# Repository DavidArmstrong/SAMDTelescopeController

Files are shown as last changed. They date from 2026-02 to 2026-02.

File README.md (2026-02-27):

# SAMDTelescopeController

## Arduino SAMD51-based Telescope Controller 4.00.00

### Main Repository Readme File

#### By David Armstrong, December 2025
 - See MIT LICENSE file

========================================================================

Note: This project is unfinished, although most of the work has been done.  I'm making it public 
so others can build on this framework. I'll continue to improve it, as I'm able to squeeze out
a few precious milliseconds over the coming months and years.

This repository implements one of many possible design scenarios for a Telescope Controller, 
using the Arduino IDE as a development environment.  It's purpose is to allow me, personally,
to use my telescope to look at stuff, instead of spending a lot of time setting it up.

I'm making this available for others to use as a reference in designing their own systems.  As
such, feel free to clone it and change as your needs dictate.

## Organization of the Repository

There are several directories in this project, each containing relevant information and code:

 - docs : Contains nearly all related documentation files for the system. (The Arduino sketches have their own Readme files.) There is a Draw.io based PNG image file showing the basic buiding blocks that make up the system, and how all the parts communicate with each other.
 - Arduino_Telescope_Interface : Eagle schematic of how to connect various interfaces.  If you have the Eagle PCB software installed, this directory should be copied to be a subdirectory under the EAGLE/projects/ directory.
 - TC4_0diagnostics : Arduino sketch designed to be used as a precursor sketch to TC4_0.  It's purpose is to help make sure all the needed software libraries are installed, and that the associated required hardware is present and working. (Completed)
 - TC4_0 : Arduino SAMD51 processor based Telescope Controller 4.00.00 sketch, that is the Telescope Controller program itself. (Still under development)
 
 Most of these have their own Readme file, and should be referenced in the order listed above, as each has
 information relevant to documents that follow them in the list.
 
 Here is a diagram of how the various hardware components relate to each other:
 
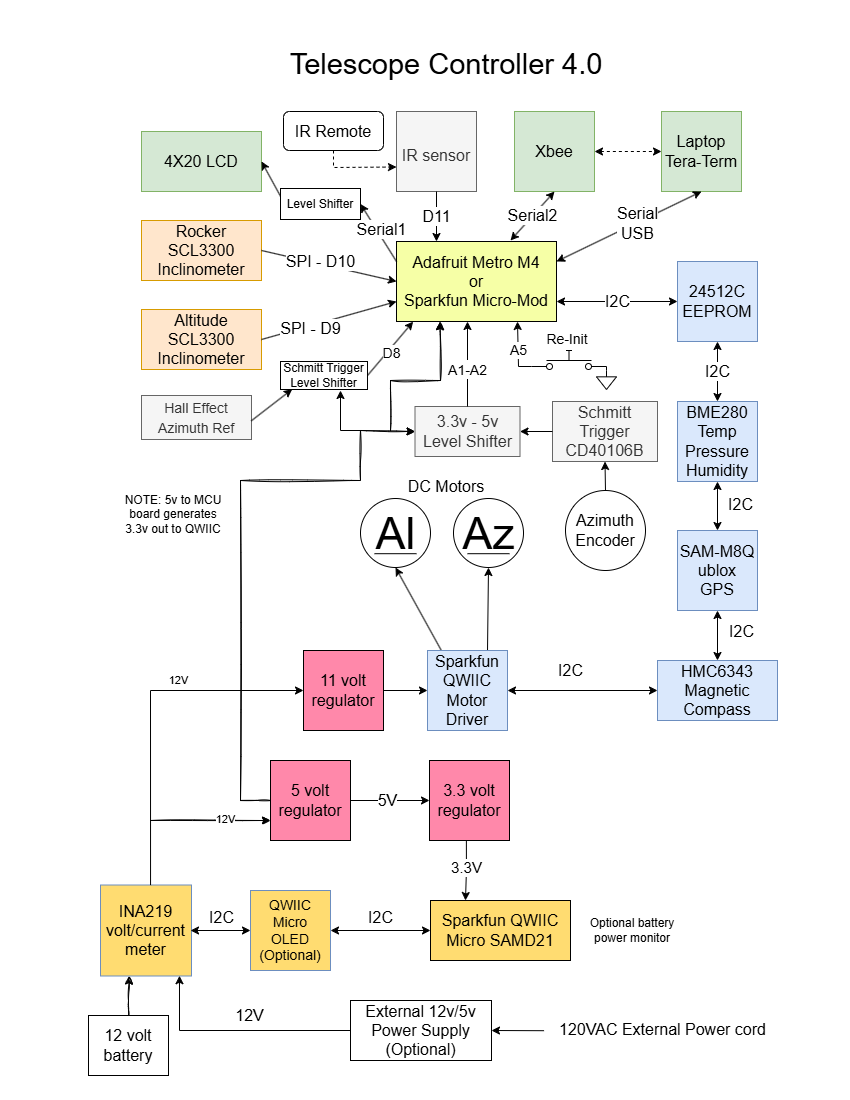
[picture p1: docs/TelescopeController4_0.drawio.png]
 
 
 <object data="Arduino_Telescope_Interface/Telescope_Interface_shield.pdf" type="application/pdf" width="700px" height="700px">
    <embed src="Arduino_Telescope_Interface/Telescope_Interface_shield.pdf">
        <p>Please download the Hardware Schematic PDF to view it: <a href="Arduino_Telescope_Interface/Telescope_Interface_shield.pdf">Hardware Schematic PDF</a>.</p>
    </embed>
</object>

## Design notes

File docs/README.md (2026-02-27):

# SAMDTelescopeController

## Arduino SAMD51-based Telescope Controller 4.00.00 Documentation

### Docs directory Readme File

#### By David Armstrong, December 2025
 - See MIT LICENSE file

========================================================================

This repository implements a SAMD51 processor based Telescope Controller, 
using the Arduino IDE as a development environment.

## Installing the Telescope Controller Application

Download this repository, and place the contained sub-directories as instructed here:

The files in the "Arduino Telescope Interface" directory contain an Eagle schematic of how to 
connect various interfaces.  If you have the Eagle PCB software installed, this directory 
should be copied to be a subdirectory under the EAGLE/projects/ directory.

There is also a draw.io based diagram showing at a high level how all the parts communicate 
with each other. This includes both the draw.io diagram source, and a 
'TelescopeController4_0.drawio.png' image file created by draw.io.

The TC4_0/, TC4_0diagnostics/, and TC4_0powerMonitor/ directories are three separate Arduino sketches, and should each be copied to the Arduino/ directory on your computer, where Arduino IDE sketch projects are stored.

## Installing the Required Arduino Libraries

As might be expected in an application this large and complex, there are a number of Arduino libraries
that have to be installed.  Most of these can be installed via the Arduino IDE Library Manager, but
not all.

Here is a list of the libraries that the Arduino IDE Library Manager knows about that must be installed:

ANSI  https://github.com/RobTillaart/ANSI <br>
CurveFitting  https://github.com/Rotario/arduinoCurveFitting <br>
Encoder  https://github.com/PaulStoffregen/Encoder <br>
extEEPROM  https://github.com/PaoloP74/extEEPROM <br>
SCL3300  https://github.com/DavidArmstrong/SCL3300 <br>
Seeed Arduino RTC  https://github.com/Seeed-Studio/Seeed_Arduino_RTC <br>
Serial Controlled Motor Driver  https://github.com/sparkfun/SparkFun_Serial_Controlled_Motor_Driver_Arduino_Library <br>
SiderealPlanets  https://github.com/DavidArmstrong/SiderealPlanets <br>
SiderealObjects  https://github.com/DavidArmstrong/SiderealObjects <br>
Sparkfun BME280  https://github.com/sparkfun/SparkFun_BME280_Arduino_Library <br>
Sparkfun MMC5983MA Magnetometer Arduino Library  https://github.com/sparkfun/SparkFun_MMC5983MA_Magnetometer_Arduino_Library <br>
Sparkfun SerLCD Arduino Library  https://github.com/sparkfun/SparkFun_SerLCD_Arduino_Library <br>
Sparkfun u-blox GNSS Arduino Library  https://github.com/sparkfun/SparkFun_u-blox_GNSS_Arduino_Library <br>
WMM_Tinier  https://github.com/DavidArmstrong/WMM_Tinier

There are also a few libraries that must be loaded directly from their on-line repositories:

AMD51 Interrupt Timer library  https://github.com/Dennis-van-Gils/SAMD51_InterruptTimer <br>
HMC6352-Arduino-Library  https://github.com/funflin/HMC6352-Arduino-Library <br>
Sparkfun HMC6343 Arduino Library  https://github.com/sparkfun/SparkFun_HMC6343_Arduino_Library <br>
IRLib2  https://github.com/cyborg5/IRLib2

NOTE: That last library, 'IRLib2', has one file that MUST have two lines modified so that
the sketch will compile successfully. In the library file at IRLibProtocols\IRLibSAMD51.h<br>
You must change lines 18-19 as follows:

```
//#define IR_TCn 3
#define IR_TCn 4
```
Also, in this same file, you must fix line 31 to add in the missing quote character at the end:

```
    #error "Unsupported output pin on Adafruit Metro M4"
```

Otherwise, if this is not done the application will NOT compile.

Finally, the optional TC4_0powerMonitor, if used, will require two additional libraries to be installed:

Adafruit INA219  https://github.com/adafruit/Adafruit_INA219 <br>
Sparkfun Micro OLED Breakout  https://github.com/sparkfun/SparkFun_Micro_OLED_Arduino_Library <br>

## Initial Testing

First use the TC4_0diagnostics.ino sketch to test the installed libraries and hardware interfaces
before going to the TC4_0.ino sketch.  The test sketch goes through each piece of hardware, 
one at a time, to make sure each can be reached and responds as expected when it is
initialized.  Please refer to the Readme file that is with that sketch for specific 
instructions on how to set up and run the application.

Note that while two or three different Magnetic Compass Libraries may loaded, only one will actually
be used by the application. It depends on which one is physically present, and on configuring
the software options.

After the TC4_0diagnostics.ino sketch tests pass, you can move on to compiling and using
the TC4_0.ino application, located in the TC4_0 folder.

Finally, as an optional utility, there is the TC4_0powerMonitor.ino sketch.  This allows real-time
monitoring of a 12 volt gel-cell battery, should that be used to power the system.  It includes
the capability of providing an estimate of how much power is available to use. The sketch is hosted
on a separate SAMD21 MCU, so it runs independently of the main controller.

Note: DO NOT ATTEMPT TO LOAD THIS CODE ONTO A STANDARD Arduino UNO BOARD.

==========================<br>
## List of Recommended Hardware
(Details are listed later in this doc.)

0. I2C EEPROM (required) - Needed to store persistent data.  Otherwise you have to either
re-enter that data every time the system is powered up, or change the code itself 
to make your data values the default. Not having this will force the program to always
start in demo mode.  (Pins SDA, SCL; IIC address 0x50)

1. Momentary Pushbutton (Leave out at your own risk) - This is used with the reset button
to force a clean re-initialization of the system should things just get into a bad state.
(i.e. Like bad values saved into the EEPROM listed in #1 above.) (Pin 19 = A5)

2. A Quadrature Optical Encoder (required) - You will need mounting hardware for this 
encoder on the Azimuth axis.  This will allow using the program, at a minimum, as Digital Setting Circles on your 
telescope.  (Pins A1,A2 for azimuth)

2a. Murata SCL3300 SPI inclinometer - You will need an inclinometer, mounted on the telescope tube, for Altitude orientation determination.
( pins 22,23,24 on ICSP header, and Chip Select Pin 9 )

3. Level shifter (required) - Needed to translate the 5 volt signals from the Azimuth encoder to
3.3 volts for the processor board.  (I haven't seen 3.3 volt quadrature encoders made yet in 
the resolutions needed for telescope positioning.)

4. I2C GPS receiver module (required) - for Time, date, elevation, Latitude and Longitude input.
(Also used for Precession correction and Sun, Moon, Planet coordinate calculations.)
 (IIC address 0x42)

All other hardware that can be added is optional, to some degree.  It depends on what 
you are willing to put up with in the dark, what you consider usable, and how much you 
can spend, in both time and money.

Consider these options:

5. Xbee modules to go wireless.
Screen output can be sent to Serial2 in the code, which will send UART
data to D4(Rx)/D7(Tx) for the SAMD51.  Using Serial2 
may be faster than relying on the Serial port, which is the default.  
The option is enabled at the top of file TC4_0.ino.  The other end of the XBee connection should have a VT100 compatible terminal emulator program.  (I use Tera-Term for Windows 11.)

6. Remove requirement for a laptop with:<br>
  A. 4x20 character LCD display (Pin D1 - Serial TX is recommended) OR use I2C bus<br>
  B. IR detector (Pin 11 = D11)<br>
  C. TV/DVD IR remote with backlit kaypad - Instant wireless handbox control

7. Refraction correction:
I2C BME280 Barometric Pressure, Temperature, Humidity Sensor (IIC address 0x77)

8. Initial telescope orientation to North:
(Not needed at all for a permanently mounted telescope.  See #13 below.  It's an aid
for portable telescopes, as it can help you find alignment stars when setting up.)
I2C Magnetic Compass (HMC6352 IIC address 0x21) 
OR (MMC5983MA IIC address 0x30)
OR (HMC6343 IIC address 0x32, 0x33 - recommended)

9. Account for mechanical level of telescope:
(Portable systems can benefit from this option.  Permanently mounted telescopes should be
mounted properly anyway, which makes this unnecessary.  See #13 below.)
Murata SCL3300 SPI inclinometer - for an Alt-Azimuth base for level determination
(pins 22,23,24 on ICSP header, and Chip Select Pin 10 )<br>

10. Separate Status display, just because I think it's cool:
I2C OLED display (IIC address 0x3c)

11. Battery supply Voltage/Current Monitoring:
(Because you really want to know how long you have before the battery dies.)
I2C Voltage/Current sensor (IIC address 0x40)

12. Motors to make your telescope a "GoTo" system:
Recommend two DC motors, rather than stepper motors.  But it's your choice.
Motor electronics - SparkFun Qwiic Motor Driver (I2C address 0x5D)
The How-To for this is your responsibility, which is why I list it as nearly dead last.  
You choose the drive system.

13. Permanently mounted telescopes can automate initialization further by installing:
Reference Sensor to determine specific Azimuth reference point in that axis.  (Pin 8)

Now if you have all that, then zero alignment stars are needed to set up the system
for an observing session.  In fact, it becomes zero alignment, mostly.  Just turn it on, let it do its setup, and tell it where to go. (I state 'mostly' because the controller still uses a tweaking star/planet on initialization to account for errors. But the system will point to that object for you.)

======================================<br>
## Detailed Hardware Information

For this system, the hardware listed below is assumed as being used.  Some substitutions
are possible, but the code might have to be changed accordingly. You will have to do your homework.

Sparkfun Mini Pushbutton switch: https://www.sparkfun.com/products/97 <br>
Hint: Consider getting a Protoshield Kit to mount these parts. It even comes with a pushbutton:  https://www.sparkfun.com/products/13820

Sparkfun Buck-Boost Converter (recommended, because one needs both 5 and 11 volt supplies): <br>
https://www.sparkfun.com/products/15208 <br>
Note: I use an additional Converter to provide a higher voltage to the Motor Controller Board to power the motors.

In addition, an extra 3.3 volt power source is required since there are a maximum number of QWIIC devices being used:<br>
(If that extra 3.3 volt supply isn't installed, the sketch is guaranteed to hang.  Or the I2C interface on the SAMD processor will burn out.  Both effects are known from experience.)<br>
https://www.sparkfun.com/products/18356 <br>
https://www.sparkfun.com/products/14495 <br>
And while you're at it, be absolutely sure that the I2C clock and data lines both have pull-up
resistors (4.7k nominal) tied to +3.3 volts.

Sparkfun bi-directional level shifter. (Used for input from two quadrature encoders.):<br>
https://www.sparkfun.com/products/12009

2 Quadrature Encoders: (Recommend US digital S2 series.)<br>
https://www.usdigital.com/products/encoders/incremental/rotary/shaft/S2 <br>
For telescope mounting hardware for encoders, try: http://skyeng.com/ <br>
They have encoders and connecting cables too.  (or 'roll your own')
And to connect the encoders cable to the processor board, use an RJ45 jack:<br>
https://www.sparkfun.com/products/716 and https://www.sparkfun.com/products/643<br>
I may also try one of these encoder kits: https://www.astrodevices.com/shop/index.php?product/page/170/Explore+Scientific+Truss+Dobsonian+Encoder+Kit

Various I2C (QWIIC) devices:  https://www.sparkfun.com/qwiic

GPS: https://www.sparkfun.com/products/15210 or for higher accuracy in RTK mode: https://www.sparkfun.com/products/15005 or https://www.sparkfun.com/products/15136

EEPROM: https://www.sparkfun.com/products/525 or https://www.sparkfun.com/products/14764

BME280 Barometric pressure/temperature sensor: https://www.sparkfun.com/products/13676 or https://www.sparkfun.com/products/14348 or the latest at https://www.sparkfun.com/products/15440 (QWIIC version - recommended)

Magnetic Compass: (Old) https://www.sparkfun.com/products/retired/7915 or you might instead try the newer version at: https://www.sparkfun.com/products/12916 (more expensive, more accurate)<br>
Newest: https://www.sparkfun.com/products/19034 (recommended)

MicroOLED display: https://www.sparkfun.com/products/14532

Battery Current/Voltage Measurement: https://www.sparkfun.com/products/15176

Motor Driver: https://www.sparkfun.com/products/13911 (older version)<br>
or https://www.sparkfun.com/products/15451 (newer version)

For the optional 4x20 LCD display, I use the older PIC based one:<br>
https://www.sparkfun.com/products/9568 <br>
Or one could substitute one of the newer ones which can be used via the UART or I2C interfaces:<br>
4x20 SerLCD/OpenLCD display: https://www.sparkfun.com/products/14074 <br>
QWIIC version: https://www.sparkfun.com/products/16398

IR detector - for use with an IR remote with backlit keypad: https://www.sparkfun.com/products/10266 or https://www.sparkfun.com/products/retired/8554 ( I bought this years ago because I knew I would use it for this project.)<br>
You choose the IR remote yourself.  I've seen them on Amazon, and Wally-World has it too.

And to avoid having to find alignment stars:<br>
SPI Murata SCL3300-D01-1 inclinometer: https://www.mouser.com/ProductDetail/Murata-Electronics/SCL3300-D01-PCB?qs=vLWxofP3U2yrcJsOYvcWaQ%3D%3D <br>
https://www.digikey.com/product-detail/en/murata-electronics-north-america/SCL3300-D01-10/490-18218-1-ND/9950619 <br>
Note: Without it, one is left with having to manually determine level the of the telescope every single time it's set up.

====================================<br>
## Supporting Documentation

EEPROM hookup guide: https://learn.sparkfun.com/tutorials/reading-and-writing-serial-eeproms <br>
Serial Enabled LCD hookup guide: https://learn.sparkfun.com/tutorials/pic-based-serial-enabled-character-lcd-hookup-guide
--> http://playground.arduino.cc/Code/SerLCD <br>
QWIIC Serial Enabled LCD hookup guide: https://learn.sparkfun.com/tutorials/avr-based-serial-enabled-lcds-hookup-guide <br>
--> The SparkFun SerLCD Arduino library can be downloaded with the Arduino library manager by searching 'SparkFun SerLCD'

====================================<br>
## History:  (Why is this Version 4?)

Version 1.0 began on that wide computer paper in 1982.  The initial
hardware was built in 1983, using a 6809 CPU at 1 MHz and 2K RAM with
64K of EPROM.  (Only 61K was available though.)
The software really didn't get to the point of being usable
until 1995 or so.  The original code was in assembly and FIG-Forth.
Version 2.0 was built in 1998 with the 68B09, so it could run at 2 MHz, with
the same 2K RAM and a larger 128K EPROM.  GAL chips were used to cut down on
chip count and allow full encoder resolution.

Version 3.0 was planned around 2003, but was never completed.  It
was based on using a Freescale HCS12XE512 MCU, running at 50 MHz.  However, when time
finally became available for software development, it was EOL (2018).  
That, and the fact that my development tools would not now work under 
Windows 10, meant I could either try rewriting my tools, or go to 
'something else'.  Several attempts at updating my Visual C++ IDE ended 
in extreme frustration.  (Thank you Microsoft!)  It was time for 'something else'.

Version 4.0 was decided on when I got my hands on a Sparkfun Redboard Turbo.
I'd always thought the Arduino line of stuff wasn't up to the task, but
this board proved me wrong.  It had real dev tools.  And it had a lot of
libraries that were tested, extensive, and readily available.  Software tool availability
often ends up determining what hardware will be used for a system.

As the software got closer to completion, it became evident that the SAMD21 memory space
was going to reach its limit.  CPU usage was getting higher as well.  The decision was made
to migrate to the SAMD51, which had twice the flash space, and nearly three times the 
raw speed. Hence the use of the Adafruit Metro M4 board. And I could still use the same
Arduino form factor protoboards I constructed that plug into the headers on those boards.

You will notice some use of 'caps' in the current source.  That's because the
Arduino code is a translation of the original FIG-Forth code, which had a 
proven record in the field, literally.  However, that Forth code was written in a
previous millenium.  Such ancient coding is considered painful to look at by
today's standards.  You are welcome to rewrite it, but I don't have the time.
There was enough rewriting done for the new system.

====================================<br>
## Bibliography:

1. Van Flandern, T. C. and K. F. Pulkkinen. "Low-Precision Formulae For
Planetary Positions."   The Astrophysical Journal Supplement Series,
Vol. 41, November 1979, P. 391-411
http://adsabs.harvard.edu/full/1979ApJS...41..391V

2. The Astronomical Almanac. Washington D. C.:
U. S. Government Printing Office. (There is an edition for each year.)

3. Duffet-Smith, Peter. Practical Astronomy With Your Calculator.
New York: Cambridge University Press, 1979.

4. Duffet-Smith, Peter. Astronomy With Your Personal Computer. New York:
Cambridge University Press, 1985.
https://oiipdf.com/astronomy-with-your-personal-computer

5.  Trueblood, Mark and Russell Genet. Microcomputer Control of
Telescopes. Richmond, Virginia: Willmann-Bell, Inc., 1985

6. Hirshfeld, Alan and Roger Sinnott. Sky Catalogue 2000.0 Volume-1:
    Stars to 8.0 Cambridge, Massachusetts: Sky Publishing Corporation, 1985

7. Hirshfeld, Alan and Roger Sinnott. Sky Catalogue 2000.0 Volume-2:
    Double Stars, Variable Stars and Nonstellar Objects Cambridge, 
    Massachusetts:  Sky Publishing Corporation, 1985
	https://heasarc.gsfc.nasa.gov/W3Browse/all/ngc2000.html

8. Taki, Toshimi. "A New Concept in Computer-Aided Telescopes."
Sky and Telescope, February 1989, P. 194-196
http://takitoshimi.starfree.jp/aim/aim.htm

9. Jean Meeus, Astronomical Formulae for Calculators, 1985, Willmann-Bell, Inc.

10. Jean Meeus, Astronomical Algorithms, 1991, Willmann-Bell, Inc.

11. Smart, W. M. Text-Book on Spherical Astronomy, 6th ed.
Cambridge, England: Cambridge University Press, 1960. Zwillinger,
D. (Ed.)

12. Taki, Toshimi. "Matrix Method for Coordinates Transformation (950KB) in pdf file". http://www.takitoshimi.shop/matrix/matrix_method_rev_e.pdf

13. Celestial Objects Online Database: http://www.astronexus.com/hyg and https://github.com/astronexus/HYG-Database

14. List of Bright Stars. https://en.wikipedia.org/wiki/List_of_brightest_stars

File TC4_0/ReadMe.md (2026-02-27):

# SAMDTelescopeController

## Arduino SAMD51-based Telescope Controller 4.00.00 Sketch

### TC4.0 Main Controller Sketch Readme File

#### By David Armstrong, December 2025
 - See MIT LICENSE.md file

=============================<br>

This folder contains the actual Telescope Controller sketch, TC4_0.ino.  There are several other
files in the folder used with this file to create the final image that is transferred to the SAMD51 flash.

The application may be used just as Digital Setting circles with no motors. But that means manually
moving the 'scope around. Of course, motors can be added later.

DO NOT ATTEMPT TO LOAD THIS CODE ONTO A STANDARD Arduino UNO BOARD.

It is assumed that the sketch under TC4_0diagnostics has already been run, and it has validated the
hardware interfaces and library installations needed.
That sketch has its own Readme file.  Its purpose was to prove that you have all the needed
libraries installed, and that the relevant hardware interfaces exist and can communicate with the
system. If one gets a library error, the code gives a URL for where each
library can be downloaded.

After the TC4_0diagnostics has run, move on to this main sketch, TC4_0.

## Tailoring the Sketch For Your System

At the beginning of the file is a section to allow setting various options and known values.

Lines 25: Azimuth Encoder count range, if known.  If not, leave defined at 0L.
If you know the encoder count range in azimuth, this value can be hardcoded and always used.  Otherwise, the system will attempt to figure out on its own what the range is.

Lines 28: Uncomment if Azimuth Encoder is changing counts backwards.

Lines 31-32: Uncomment if associated Motor is moving backwards.

Line 36: Default Time Zone, usually in the range -12.0 to +12.0. This is in hours offset from GMT.

Lines 38-39: Daylight saving usage - Automatically figures out if DST is active or not in US locations only.

Lines 47, 50: Select Terminal display output, either Serial (USB) or Serial2 (XeeBee module)

Line 55: Select LCD output. Defaults to Serial1.

Lines 58, 60: Select which type of Magnetic Compass Sensor is in use.

Line 65 : Select offset into EEPROM that persistent data values are recorded.  Usually this is '0'.

Other options can be set inside the sketch itself while it is running. Those options are set to default settings
defined in tcinit.ino.

## Sketch Output

On a Windows computer, one can use the terminal program Tera-Term to access the board via USB.
However, any VT-100 compatible terminal program should work with the sketch.
Do not use the default Arduino IDE Serial output window, as it does not handle VT-100 control codes.

The Reset button may need to be pressed after programming via the Arduino IDE to see the 
program output from the beginning.

Reference: 
https://learn.sparkfun.com/tutorials/terminal-basics/tera-term-windows

==========================<br>
## Software Behavior

The primary design focus has been to require as little input as possible from the user to set up. A telescope should be as easy as a toaster to use, and not require the training and agility of an astronaut.

1. Make it wireless.  Battery power is on the telescope itself, not external to it. So no visible wires.
2. No alignment star hunting, if at all possible.
3. No input of parameters, other than what is needed to specify the object to look at.

The system allows three options for user interfaces.  There can be some overlap. These are set in the file TC4_0.ino,
or internally in the sketch itself as a selectable option when it is run.

A. Use the USB interface to the processor board.  It's the default, but requires a USB cable. (Serial)
B. Use Xbee hardware to allow a wireless serial connection to the system. (Serial2)
   This is useful when running Tera-Term on a connected Windows laptop.
C. Use an LCD display with IR remote for input. (Serial1 or I2C)
   No external cabling required for this option.

One has to choose either A or B.  Option C can be used by itself, but one of the
other methods has to initially at least be designated as well.

When the system first powers on, it detects what is connected, and adapts as it can accordingly.

To that end, there should be an Azimuth Reference Sensor provided on the telescope mount.  This can be either a switch, light sensor, or magnetic Hall-effect sensor.  Otherwise, the program will ask for manual help in initialization. An inclinometer can be added to the rocker board to help level the telescope in azimuth, and the system will prompt for that when it is ready.  Note that placement of the Azimuth Reference sensor should be such so that it permits leveling adjustments to be done when the telescope is at that position.

The altitude axis needs an SCL3300 inclinometer installed on the telescope tube itself.

====================================<br>

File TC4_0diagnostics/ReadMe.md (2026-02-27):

# SAMDTelescopeController

## Arduino SAMD51-based Telescope Controller 4.00.00 Diagnostics Sketch

### TC4.0 Diagnostics Sketch Readme File

#### By David Armstrong, December 2025
 - See MIT LICENSE.md file

==================================================================

This Sketch is designed to be used as a precursor sketch to TC4_0,
the SAMD51 processor based Telescope Controller 4.00.00 sketch.

Its purpose is to verify that all the needed software libraries
are installed, and that the associated required hardware is present and
working.

The application requires a SAMD51 based processor:<br>
Option 1: Adafruit Metro M4 - based on SAMD51 (Used in my tests)<br>
https://www.adafruit.com/product/3382 <br>
Option 2: Sparkfun Micro-Mod system with SAMD51 processor<br>
https://www.sparkfun.com/products/16791 <br>
https://www.sparkfun.com/products/16885 

Any SAMD51 processor Arduino compatible board should work to some degree.

For the Metro M4, you MUST set up the Arduino IDE precisely as listed on the Adafruit guide 
for that board:<br>
https://learn.adafruit.com/adafruit-metro-m4-express-featuring-atsamd51

For the Metro M4 board with the SAMD51 processor, it is also recommended to select the 'Fastest'
compile speed option on the Arduino IDE.  This is located at: Tools > Optimize > Fastest, and is
available only after selecting the Metro M4 as the target board.  This 
doesn't make the compile time shorter, but it does make the sketch run faster on the processor.
We do this on the SAMD51 because there is not a memory constraint on that system. (We swap 
some memory space for speed of execution increases.)

## Tailoring the Sketch For Your System

At the beginning of the file is a section to allow setting various options and known values.
If any of these are changed, identical changes will need to be made in the TC4_0.ino sketch.

Line 18: LCDpicflag - Set to 'true' for older PIC based LCD, 'false' for newer AVR based LCD. This sketch assumes that Serial1 is used to communicate with the LCD display, if used.

Lines 21-22: Uncomment if associated Encoder is changing counts backwards.

Lines 25-26: Uncomment if associated Motor is moving backwards.

Line 29: Comment out if not using old HMC6352 magnetic compass. The sketch assumes the use of SFE_MMC5983MA by default.

Line 31: Comment out if not using the HMC6343 magnetic compass.

Lines 43-55: Provided for reference on Arduino Pin Usage in this project.

## Preparing The Libraries

All of the libraries referenced in the sketch have to be available
before the sketch will compile successfully. If the sketch compiles 
and loads, you have the needed libraries.  However,
if you get an error, the source code lists a URL to go to
download the missing library.

NOTE: In the library file at IRLibProtocols\IRLibSAMD51.h<br>
You must change lines 18-19 as follows:

```
//#define IR_TCn 3
#define IR_TCn 4
```
Also, in this same file, you must fix line 31 to add in the missing quote character at the end:

```
    #error "Unsupported output pin on Adafruit Metro M4"
```

Otherwise, the application will NOT compile.

DO NOT ATTEMPT TO LOAD THIS CODE ONTO A STANDARD Arduino UNO BOARD.

## Sketch Output

On a Windows computer, you can use the terminal program Tera-Term to access the board via USB.
However, any VT-100 compatible terminal program should work with the sketch.
The default Arduino IDE Serial output window can also be pressed into service here.

You may need to press the Reset button after programming via the Arduino IDE to see the 
program output from the start of the sketch.

Reference: 
https://learn.sparkfun.com/tutorials/terminal-basics/tera-term-windows

## Tests that are Run

The following is a list of all the tests run by the sketch:

0. Sketch Start means required libraries are installed.  A compile fail will occur if a library is missing.  The code includes the URL to use to fetch each library, as a comment, with each statement that references a library.

1a. Output to VT-100 compatible terminal application via USB using Serial.

1b. Output to 4x20 character LCD using Serial1.

1c. Output to VT-100 compatible terminal application via Xee-Bee using Serial2.

2. Input via either Serial and/or Serial2. Use a Carriage Return/Enter key to terminate the test.

3. Azimuth Encoder check. Counts must increase when going from North to East to South to West.
If not, uncomment line #define SWAP_AZIMUTH_ENCODER_AB<br>
Use a Carriage Return/Enter key to terminate the test.

4. Verify presence of I2C EEPROM.

5. u-blox GPS module detection.

6. Detects rocker (optional) Murata SCL3300 Inclinometer Sensor.

7. Detects tube/Altitude (required) Murata SCL3300 Inclinometer Sensor.

8. Magnetic Compass detection. Can check for MMC5983MA, HMC6352, or HMC6343.

9. BME280 Temperature, Pressure,Humidity Sensor detection.

10. Azimuth Reference Sensor Detection. The test will indication if the digital line is HIGH or LOW.
Use a Carriage Return/Enter key to terminate the test.

11. Lock/Reinitialize Switch Detection. The test will indication if the digital line is HIGH or LOW.
Use a Carriage Return/Enter key to terminate the test.

12. I2C Serial Controlled Motor Driver Board detection and Motor tests. Sketch output provides instructions on how the motors should move for this test.

13. IR Remote Receiver functionality check.

Once these tests pass to your satisfaction, you are ready to proceed to the TC4_0 sketch, which is the 
actual Telescope Controller application.

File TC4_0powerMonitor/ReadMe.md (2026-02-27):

# SAMDTelescopeController

## Arduino SAMD21-based Telescope Controller 4.00.00 Power Monitor Sketch

### TC4.0 Power Monitor Sketch Readme File

#### By David Armstrong, February 2026
 - See MIT LICENSE.md file

=============================<br>

This sketch is optional, but useful.  It provides real-time monitoring of
a 12 volt Gel cell battery capacity that could be used to power the telescope controller.
It uses an Adafruit INA219 voltage/current sensor, and an OLED display. It is
designed to use its' own SAMD21 MCU, so as to not add any additional load onto
the main telescope controller MCU.

There are no other parts, besides the SAMD21 MCU, the INA219 sensor and the OLED display for output.
Connections between the three parts are via QWIIC cabling, which can be daisy chained from one to the other device.

The output displayed is as follows:

V: Output voltage of the battery <br>
mA: Current usage in milliamps <br>
mAH: Power draw in milliamp-hours <br>
mW: Power used in milliwatts <br>
%: Percentage estimate of how much power is left to use <br>

If a 120 volt power supply is being used to provide power to the system, then the percent power left
makes no sense.  The other values being reported though are still of use to the observer.

Libraries used: <br>
Adafruit INA219  https://github.com/adafruit/Adafruit_INA219 <br>
Sparkfun Micro OLED Breakout  https://github.com/sparkfun/SparkFun_Micro_OLED_Arduino_Library <br>

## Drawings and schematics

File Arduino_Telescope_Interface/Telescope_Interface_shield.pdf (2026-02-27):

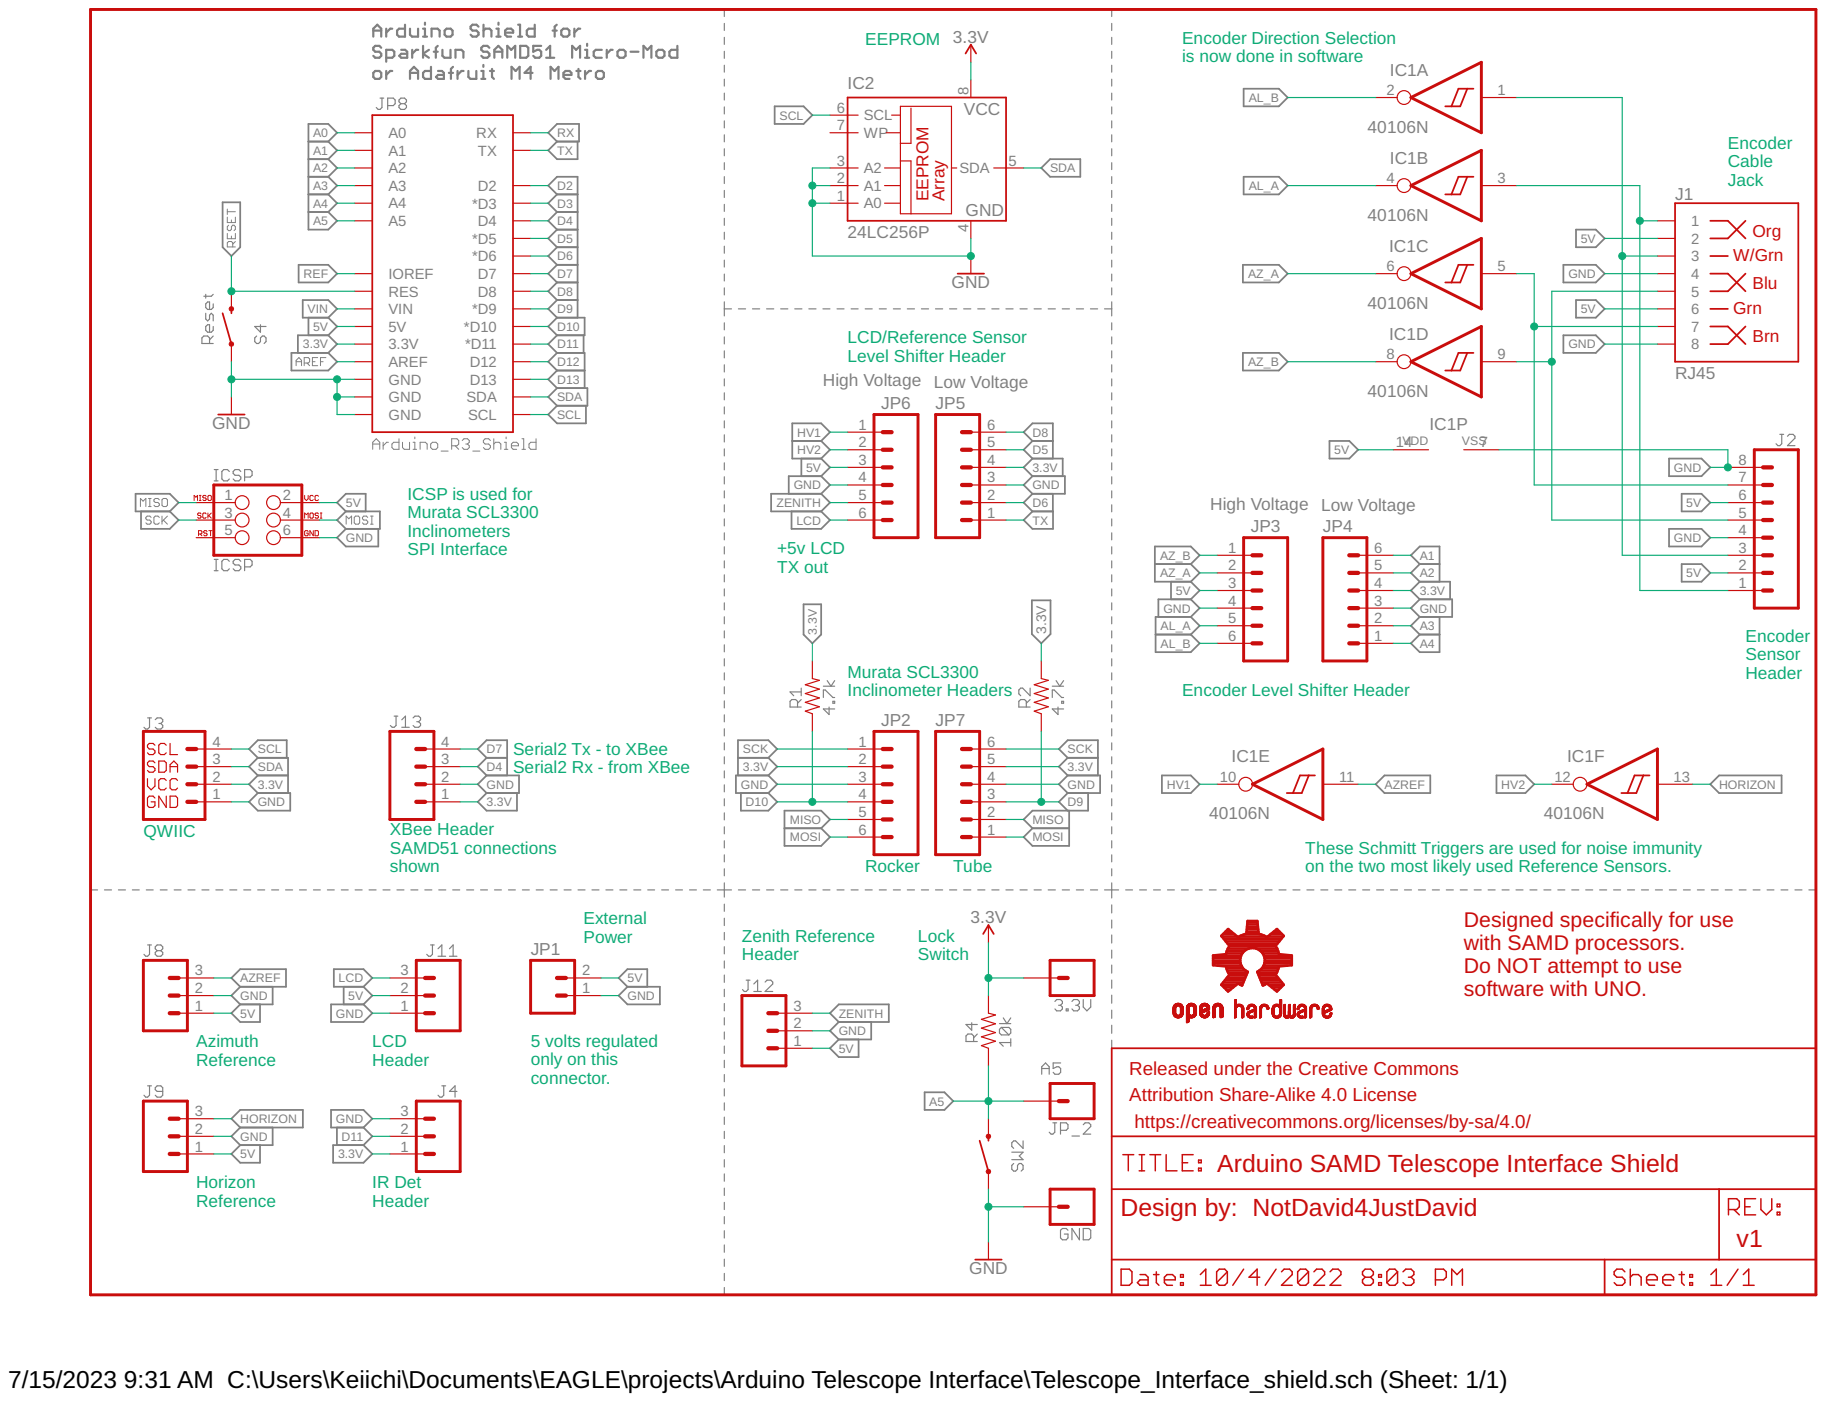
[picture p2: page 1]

Encoder Direction Selection
is now done in software

LCD/Reference Sensor Level Shifter Header

High Voltage Low Voltage

ICSP is used for Murata SCL3300

Encoder Sensor Header Encoder Level Shifter Header

These Schmitt Triggers are used for noise immunity on the two most likely used Reference Sensors.

Designed specifically for use
with SAMD processors. Do NOT attempt to use

software with UNO. Released under the Creative Commons Attribution Share-Alike 4.0 License

https://creativecommons.org/licenses/by-sa/4.0/

7/15/2023 9:31 AM C:\Users\Keiichi\Documents\EAGLE\projects\Arduino Telescope Interface\Telescope_Interface_shield.sch (Sheet: 1/1)

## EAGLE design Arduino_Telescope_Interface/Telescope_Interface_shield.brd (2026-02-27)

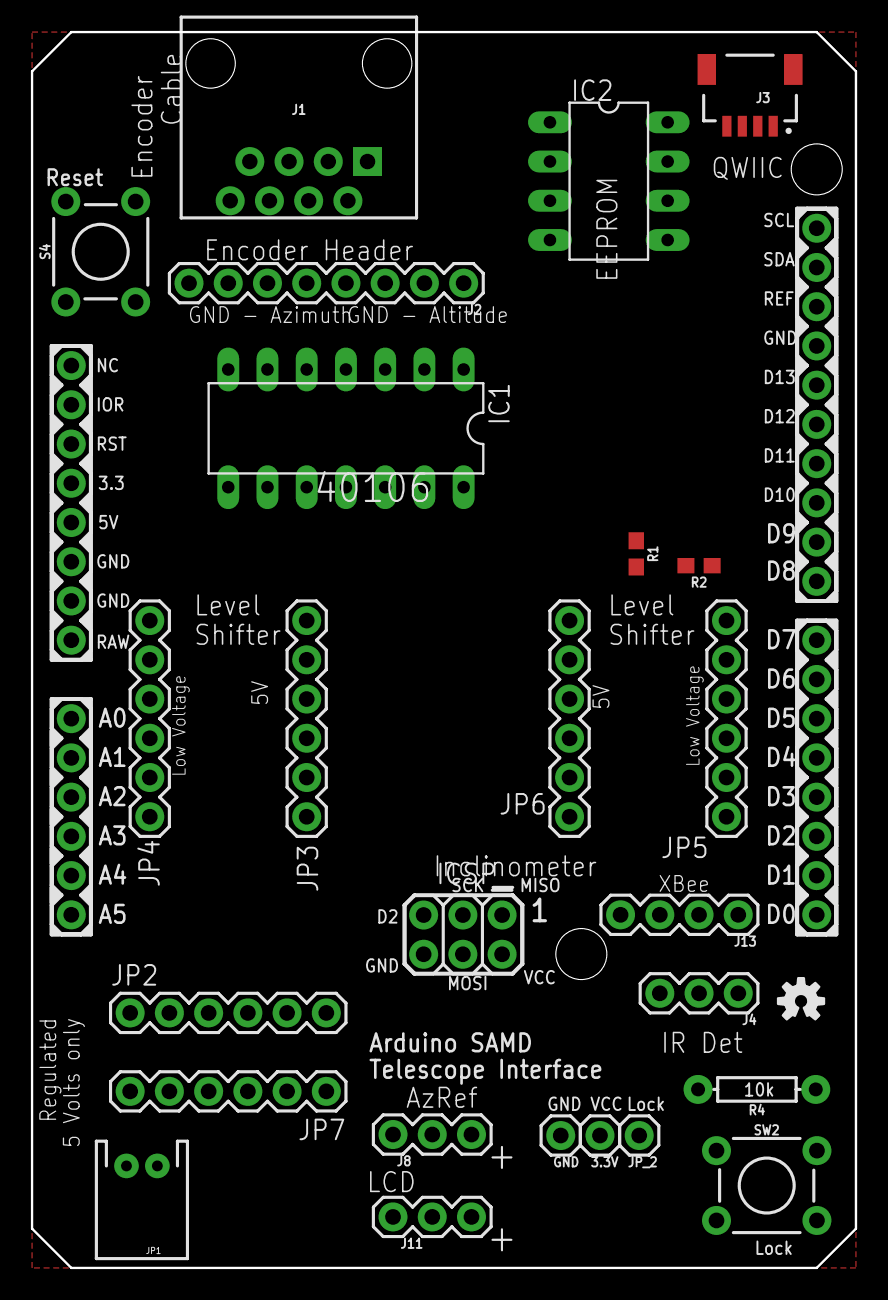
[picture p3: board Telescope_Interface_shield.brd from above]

Board: 2 copper layers, 53.3 x 80.0 mm, 28 parts (0 on the bottom side), 35 nets, no tracks yet.

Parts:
3.3V: 1X01
FRAME1: FRAME-LETTER; CREATIVE_COMMONS
GND: 1X01
IC1: 40106N; DIL14
IC2: 24LC256P; DIL8
ICSP: ICSP; 2X3
J1: RJ45; RJ45-8
J2: 1X08
J3: JST04_1MM_RA
J4, J8, J11: 455-1750-1-ND; 1X03
J13: 1X04
JP1: JST-2-PTH
JP2, JP3, JP4, JP5, JP6, JP7: 1X06
JP8: ARDUINO_R3_SHIELDR3_PROTO_SHIELD; UNO_R3_PROTO_SHIELD
JP_2: 1X01
LOGO1: OSHW-LOGOS; OSHW-LOGO-S
R1, R2: 4.7k; 0603
R4: 10k; AXIAL-0.3
S4: MOMENTARY-SWITCH-SPST-PTH-6.0MM; TACTILE_SWITCH_PTH_6.0MM
SW2: MOMENTARY-SWITCH-SPST-PTH-6.0MM; TACTILE_SWITCH_PTH_6.0MM

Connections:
3.3V: 3.3V.1, IC2.8, ICSP.2, J3.2, J4.1, J13.1, JP2.2, JP4.4, JP5.4, JP7.5, JP8.3.3V, R1.2, R2.2, R4.P$2
5V: IC1.14, J1.2, J1.6, J2.2, J2.6, J8.1, J11.2, JP1.2, JP3.3, JP6.3, JP8.5V
A1: JP4.6, JP8.A1
A2: JP4.5, JP8.A2
A3: JP4.2, JP8.A3
A4: JP4.1, JP8.A4
A5: JP8.A5, JP_2.1, R4.P$1, SW2.3
AL_A: IC1.4, JP3.5
AL_B: IC1.2, JP3.6
AZREF: IC1.11, J8.3
AZ_A: IC1.6, JP3.2
AZ_B: IC1.8, JP3.1
D4: J13.3, JP8.D4
D5: JP5.5, JP8.D5
D6: JP5.2, JP8.D6
D7: J13.4, JP8.D7
D8: JP5.6, JP8.D8
D9: JP7.3, JP8.D9, R2.1
D10: JP2.4, JP8.D10, R1.1
D11: J4.2, JP8.D11
GND: GND.1, IC1.7, IC2.1, IC2.2, IC2.3, IC2.4, ICSP.6, J1.4, J1.8, J2.4, J2.8, J3.1, J4.3, J8.2, J11.1, J13.2, JP1.1, JP2.3, JP3.4, JP4.3, JP5.3, JP6.4, JP7.4, JP8.GND@0, JP8.GND@1, JP8.GND@2, S4.1, SW2.1
HV1: IC1.10, JP6.1
HV2: IC1.12, JP6.2
LCD: J11.3, JP6.6
MISO: ICSP.1, JP2.5, JP7.2
MOSI: ICSP.4, JP2.6, JP7.1
unnamed: IC1.3, J1.1, J2.1
unnamed: IC1.1, J1.3, J2.3
unnamed: IC1.5, J1.7, J2.7
unnamed: IC1.9, J1.5, J2.5
RESET: JP8.RES, S4.3
SCK: ICSP.3, JP2.1, JP7.6
SCL: IC2.6, J3.4, JP8.SCL
SDA: IC2.5, J3.3, JP8.SDA
TX: JP5.1, JP8.TX

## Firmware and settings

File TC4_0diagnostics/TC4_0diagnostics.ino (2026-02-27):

/* Arduino SAMD-based Telescope Controller 4.00.00 Diagnostics - February 2026
// See MIT LICENSE.md file and ReadMe.md file for essential information
// Highly tailored to the AdaFruit M4 Metro
// DO NOT ATTEMPT TO LOAD THIS ONTO A STANDARD UNO
//
// This sketch should be used to verify software library installation
// and hardware connections before attempting to use the TC4_0.ino sketch */

//****** Update the Defines in this section, as needed ********

/* NOTE: In the library file at IRLibProtocols\IRLibSAMD51.h
// You must change lines 18-19 as follows:
//#define IR_TCn 3
#define IR_TCn 4
// Otherwise, the application will NOT compile */

// Set to 'true' for older PIC based LCD, 'false' for newer AVR based LCD
#define LCDpicflag true

// Uncomment if associated Encoder is changing counts backwards
//#define SWAP_AZIMUTH_ENCODER_AB

// Uncomment if associated Motor is moving backwards
//#define REVERSE_AZIMUTH_MOTOR_DIRECTION
//#define REVERSE_ALTITUDE_MOTOR_DIRECTION

// Comment out if not using old HMC6352 magnetic compass
//#define __HMC6352__
// Comment out if not using the new HMC6343 magnetic compass
#define __HMC6343__

//****** End of User Defined Section ******************************************

// Account for Weirdness with SerialUSB
#if defined(ARDUINO_SAMD_ZERO) && defined(SERIAL_PORT_USBVIRTUAL)
#define Serial SERIAL_PORT_USBVIRTUAL
#endif
#define TCterminal Serial
#define TC_LCD Serial1

// Arduino Digital Pin Usage declarations
// D7 = Serial2 Tx - to XBee Green (SAMD51) */
const int AZREFsensor = 8; /* D8 - Azimuth axis reference point */
const int SPI_SS2 = 9; // D9 - telescope tube Altitude inclinometer sensor select
const int SPI_SS1 = 10; // D10 - Rocker Base inclinometer sensor select
// IR Detector Pin - Use TV/DVD IR Remote as a handbox control
const int IR_RECVpin = 11; /* D11 - IR Remote sensor */
#define RAAZ_pinA   15
#define RAAZ_pinB   16
const int LOCKBTN = 19; /* A5 */
// define IR receive pin - for IR Remote Library routines
int RECV_PIN = IR_RECVpin;

const char hitkey[] = "Hit Key to continue";
const int MotorDriver_ADR = 0x5D; //Qwiic Motor Driver
// Motor Defines to make it more readable
#define ALTITUDE_MOTOR 0
#define AZIMUTH_MOTOR 1
#define CW_DIRECTION 0
#define CCW_DIRECTION 1
#define STOP_SPEED 0
#define SLOW_SPEED 5
#define FAST_SPEED 255

//===========================================
// Test required library installation
#ifndef __Libraries__
#include <Encoder.h> // https://github.com/PaulStoffregen/Encoder

#include "wiring_private.h"

#include <Arduino.h>

#include "pins_arduino.h"

#include <Wire.h>
#include <stdint.h>
#include <string.h>

#include "RTC_SAMD51.h" // https://github.com/Seeed-Studio/Seeed_Arduino_RTC
#include "DateTime.h"

#include <math.h>
#include "SiderealPlanets.h" // https://github.com/DavidArmstrong/SiderealPlanets
#include "SiderealObjects.h" // https://github.com/DavidArmstrong/SiderealObjects
#include <curveFitting.h> // https://github.com/Rotario/arduinoCurveFitting
#include "WMM_Tinier.h" // https://github.com/DavidArmstrong/WMM_Tinier

#include "extEEPROM.h" // https://github.com/PaoloP74/extEEPROM

#include <SerLCD.h> // https://github.com/sparkfun/SparkFun_SerLCD_Arduino_Library

#include "ansi.h" // https://github.com/RobTillaart/ANSI

#include <SparkFun_u-blox_GNSS_Arduino_Library.h> // https://github.com/sparkfun/SparkFun_u-blox_GNSS_Arduino_Library
#include "SparkFunBME280.h" // https://github.com/sparkfun/SparkFun_BME280_Arduino_Library

#include <IRLibDecodeBase.h> // https://github.com/cyborg5/IRLib2 
#include <IRLib_P01_NEC.h>   // Now include only the protocols you wish
#include <IRLib_P02_Sony.h>  // to actually use. The lowest numbered
#include <IRLib_P07_NECx.h>  // must be first but others can be any order.
//#include <IRLib_P09_GICable.h>
//#include <IRLib_P11_RCMM.h>
#include <IRLibCombo.h>     // After all protocols, include this
// All of the above automatically creates a universal decoder
// class called "IRdecode" containing only the protocols you want.
// Now declare an instance of that decoder.
IRdecode irdecoder;
// Include a receiver either this or IRLibRecvPCI or IRLibRecvLoop
#include <IRLibRecv.h>

#include "SCMD.h" // https://github.com/sparkfun/Serial_Controlled_Motor_Driver
#include "SCMD_config.h"

// Magnetic Compass Libraries
#ifdef __HMC6352__
#include <HMC6352.h> // https://github.com/funflin/HMC6352-Arduino-Library
#endif
#ifdef __HMC6343__
#include "SFE_HMC6343.h" // https://github.com/sparkfun/SparkFun_HMC6343_Arduino_Library
#endif
#include <SparkFun_MMC5983MA_Arduino_Library.h> // https://github.com/sparkfun/SparkFun_MMC5983MA_Magnetometer_Arduino_Library

#include <SPI.h>
#include "SCL3300.h" // https://github.com/DavidArmstrong/Arduino-SCL3300

//============================
// Hardware/Software Declarations
// Serial2 is second UART port for Xbee wireless ANSI terminal, as an alternative to Serial
#define PIN_SERIAL2_RX 4    /* PB13 */
#define PAD_SERIAL2_RX (SERCOM_RX_PAD_1)
#define PIN_SERIAL2_TX 7    /* PB12 */
#define PAD_SERIAL2_TX (UART_TX_PAD_0)
Uart Serial2( &sercom4, PIN_SERIAL2_RX, PIN_SERIAL2_TX, PAD_SERIAL2_RX, PAD_SERIAL2_TX );
Stream *SERIALOUT = &Serial2;

#ifndef SWAP_AZIMUTH_ENCODER_AB
Encoder RAAZenc( RAAZ_pinA , RAAZ_pinB ); //Incremental Quadrature Encoder for RA/Aximuth
#else
Encoder RAAZenc( RAAZ_pinB , RAAZ_pinA ); //Incremental Quadrature Encoder for RA/Aximuth
#endif

IRrecv irrecv(RECV_PIN);  //pin number for the receiver
RTC_SAMD51 rtczero;

const int PIN_RESET = 44;
#define DC_JUMPER 1

BME280 bme280; //Temperature, Barometric Pressure, Humidity Sensor
SFE_UBLOX_GNSS ubloxGPS;

// IIC address of EEPROM - 24LC256 or 24C512C-L */
//const int EEPROM_ADR = 0x55;
const int EEPROM_ADR = 0x50;
boolean I2CEEPROMpresent, GPSpresent, BMEpresent;
// 256 kbits = 32K bytes for EEPROM
//extEEPROM tcEEPROM(kbits_256, 1, 64, EEPROM_ADR);
// 512 kbits = 64K bytes for EEPROM
extEEPROM tcEEPROM(kbits_512, 1, 64, EEPROM_ADR);

SiderealPlanets myAstro;
SiderealObjects myObjects;
boolean MotorDriverflag;
SCMD i2cMotorDriver; //Serial Controlled Motor Driver

double FMAGHDG; // Magnetic Compass heading
#ifdef __HMC6343__
SFE_HMC6343 dobHMC6343; // Declare the compass object
#endif
SFE_MMC5983MA MMC5983MAmag;
WMM_Tinier myDeclination;
SCL3300 rockerTilt, tubeTilt; // inclinometers
ANSI ansi(&TCterminal); // VT100 support
ANSI ansi2(&Serial2); // VT100 support
#endif

/* Function declarations
// And for SAMD51 - can't use sercom5, 3, or 2
// sercom3 - Serial1 on D0/D1
// sercom5 - I2C pins for SCL/SDA
// sercom2 - SPI */
void SERCOM4_0_Handler() { Serial2.IrqHandler(); }
void SERCOM4_1_Handler() { Serial2.IrqHandler(); }
void SERCOM4_2_Handler() { Serial2.IrqHandler(); }
void SERCOM4_3_Handler() { Serial2.IrqHandler(); }

void newdelay( long interval ) {
  // delay without blocking
  // See https://www.arduino.cc/en/tutorial/BlinkWithoutDelay
  // Generally, you should use "unsigned long" for variables that hold time
  // The value will quickly become too large for an int to store
  unsigned long previousMillis = millis();
  unsigned long currentMillis = millis();

  while (currentMillis - previousMillis < interval) {
    currentMillis = millis();
  }
}

void TERMclear() {
  //Clear VT100 screen and home cursor
  ansi.clearScreen();
  ansi2.clearScreen();
}

void LCDclear() { // Clear display and home cursor
  if (LCDpicflag) {
    // PIC based LCD on TC_LCD TxD line
    TC_LCD.write(0xfe); // = 254 decimal
    TC_LCD.write(0x01);
  } else {
    // OpenLCD on TC_LCD TXD line
    TC_LCD.write('|'); //Send setting character = 124 = 0x7c
    TC_LCD.write('-'); //Send clear display character
  }
}

char KEY() { // return a character of input from any source
  char n = ' ';
  long xnL;
  boolean rcvd = false;

  do {
    if (TCterminal.available()) {
      n = TCterminal.read();
      rcvd = true;
    } else if (Serial2.available()) {
        n = Serial2.read();
        rcvd = true;
    }
  } while (rcvd == false);
  return n;
}

void LCDprint(char tmp) { TC_LCD.print(tmp); }
void LCDprint(const char* tmp) { TC_LCD.print(tmp); }

int ACCEPT(char *buf, int limit) {
  // read a line from input into buffer, return char count
  int x;
  int ptr = 0;
  *buf = 0;

  for (x = 0; x < limit; x++) {
    buf[x] = 0;
  }
  while (1) {
    x = KEY();
    if (x == 0x0D) { // cr == end of line
      buf[ptr] = 0; // flag end of line
      return ptr; // return char count
    }
    if (x == 0x08) { // backspace
      if (ptr > 0) {
        ptr--;
        buf[ptr] = 0;
        TCterminal.print ("\b \b"); // erase bs'd char
        Serial2.print("\b \b"); // erase bs'd char
      }
    } else {
      if (ptr < (limit - 1)) {
        TCterminal.print ((char) x); // echo char
        Serial2.print ((char) x); // echo char
        buf[ptr] = x; // store in buffer
        ptr++;
      }
    }
  }
}

void setup() {
  // Test 0 - Start means required libraries are installed
  Serial.begin(9600); //May use VT100 compatible terminal emulator
  while (!Serial && !Serial2); //Wait for user to open terminal
  newdelay(2000);
  TERMclear();
  TCterminal.println(" Telescope Controller 4.0 Hardware Diagnostics Sketch.");
  TCterminal.println(" Required Arduino Libraries are installed successfully\n");
  
  
  // Test 1A - Terminal outputs
  TCterminal.println(" Start with Test of Serial Output. ( Which you see here. )");
  TCterminal.println(" Default USB Serial Interface is working\n");
  TCterminal.println(" Initialize I2C.\n");
  Wire.begin(); // I2C init
  TCterminal.println(" Initialize Serial1 for LCD 4x20 char display.\n");
  Serial1.begin(9600); // serial 4x20 LCD display

  // For SAMD51 Serial2
  TCterminal.println(" Initialize Serial2 for XeeBee interface.\n");
  pinPeripheral(4, PIO_SERCOM); // Define Pins for Serial2 UART port
  pinPeripheral(7, PIO_SERCOM);
  TCterminal.println(" Do Serial2 begin().\n");
  Serial2.begin(9600);
  newdelay(1600); // Give time for Serial2 to init

  TCterminal.println(" Initialize limits and pushbutton inputs.\n");
  pinMode(LED_BUILTIN, OUTPUT);
  pinMode(AZREFsensor, INPUT_PULLUP);
  pinMode(LOCKBTN, INPUT_PULLUP);
  newdelay(1600); // Give time to see this.

  
  // Test 1B - LCD outputs
  LCDclear();
  TC_LCD.print("Telescope Controller 4.0 Diagnostics Sketch - LCD working ");
  Serial2.println("Telescope Controller 4.0 Diagnostics Sketch - XeeBee");
  Serial2.println("\nRequired Arduino Libraries are installed successfully");
  Serial2.println("Alternate Xbee Wireless Serial Interface is working\n");


  // Test 2 - Terminal input
  TCterminal.println("Type letters to test input - Enter when done:");
  Serial2.println("Type letters to test input - Enter when done:");
  char PAD[80];
  ACCEPT(PAD, 80); //Get 80 chars max
  TCterminal.println("\n\rInput Test done\n");
  Serial2.println("\n\rInput Test done\n");


  // Test 3 - Azimuth Encoder check
  TCterminal.println("\nAzimuth Encoder check");
  Serial2.println("\nAzimuth Encoder check");
  TCterminal.println("Counts must increase when going from North to East to South to West!");
  Serial2.println("Counts must increase when going from North to East to South to West!");
  TCterminal.println("If not, uncomment line #define SWAP_AZIMUTH_ENCODER_AB");
  Serial2.println("If not, uncomment line #define SWAP_AZIMUTH_ENCODER_AB");
  TCterminal.println(hitkey);
  Serial2.println(hitkey);
  RAAZenc.write(0L);
  long RAAZ;
  while (!(TCterminal.available() || Serial2.available())) {
    RAAZ = RAAZenc.read();
    TCterminal.print("Azimuth Encoder Position: ");
    Serial2.print("Azimuth Encoder Position: ");
    TCterminal.println(RAAZ);
    Serial2.println(RAAZ);
    newdelay(100);
    ansi.cursorUp(1);
    ansi2.cursorUp(1);
  }
  KEY();
  TCterminal.println("");
  Serial2.println("");
  
  
  // Test 4 - EEPROM detect - verify presence of I2C EEPROM
  byte EEPROMstatus = tcEEPROM.begin(extEEPROM::twiClock100kHz);
  I2CEEPROMpresent = true;
  TCterminal.print("I2C EEPROM ");
  Serial2.print("I2C EEPROM ");
  if ( EEPROMstatus != 0 ) {
    I2CEEPROMpresent = false;
    TCterminal.print("*NOT* ");
    Serial2.print("*NOT* ");
  }
  TCterminal.println("detected.\n");
  Serial2.println("detected.\n");
  TCterminal.println(hitkey);
  Serial2.println(hitkey);
  KEY();
  TCterminal.println("");
  Serial2.println("");


  // Test 5 - u-blox GPS detection
  TCterminal.print("u-blox GPS module ");
  Serial2.print("u-blox GPS module ");
  if ((ubloxGPS.begin() == false) || !I2CEEPROMpresent ) {
    TCterminal.print("*NOT* ");
    Serial2.print("*NOT* ");
  }
  TCterminal.println("detected.");
  Serial2.println("detected.");
  TCterminal.println(hitkey);
  Serial2.println(hitkey);
  KEY();
  TCterminal.println("");
  Serial2.println("");


  // Test 6 - Leveling Murata SCL3300 Inclinometer Sensor detection
  TCterminal.print("Rocker (Leveling) Murata SCL3300 inclinometer ");
  Serial2.print("Rocker (Leveling) Murata SCL3300 inclinometer ");
  if (!rockerTilt.begin(SPI_SS1)) {
    TCterminal.print("not ");
    Serial2.print("not ");
  } else {
	rockerTilt.powerDownMode();
  }
  TCterminal.println("detected.");
  Serial2.println("detected.");
  TCterminal.println(hitkey);
  Serial2.println(hitkey);
  KEY();
  TCterminal.println("");
  Serial2.println("");

  
  // Test 7 - Altitude Murata SCL3300 Inclinometer Sensor detection
  TCterminal.print("Tube (Altitude) Murata SCL3300 inclinometer ");
  Serial2.print("Tube (Altitude) Murata SCL3300 inclinometer ");
  if (tubeTilt.begin(SPI_SS2)) {
    TCterminal.println("detected.");
    Serial2.println("detected.");
    // Put this inclinometer into Mode 1, since we are using it to measure 0-90 Degree angles
    tubeTilt.setMode(1);
    TCterminal.print("Tube Murata SCL3300 inclinometer ");
    Serial2.print("Tube Murata SCL3300 inclinometer ");
    if (tubeTilt.begin(SPI_SS2)) {
      TCterminal.print("now in");
      Serial2.print("now in");
    } else {
      TCterminal.print("failed to transition to");
      Serial2.print("failed to transition to");
    }
    TCterminal.println(" Mode 1.");
    Serial2.println(" Mode 1.");
	tubeTilt.powerDownMode();
  } else {
    TCterminal.println("not detected.");
    Serial2.println("not detected.");
  }
  TCterminal.println(hitkey);
  Serial2.println(hitkey);
  KEY();
  TCterminal.println("");
  Serial2.println("");


  // Test 8 - Several types of Magnetic Compass detection
  TCterminal.println("\nCheck for various magnetic compass hardware:");
  Serial2.println("\nCheck for various magnetic compass hardware:");
  FMAGHDG = 500.0;
#ifdef __HMC6352__
  HMC6352.Wake();  // This is the really old EOL compass
  newdelay(20);
  FMAGHDG = HMC6352.GetHeading();
  HMC6352.Sleep();
#endif
  if (FMAGHDG > 360.1) { //Old Magnetic Compass not detected at default I2C address
    TCterminal.println("HMC6352 Magnetic Compass not detected.");
    Serial2.println("HMC6352 Magnetic Compass not detected.");

    //* Initialize the HMC6343 and verify its physical presence
#ifdef __HMC6343__
    if (dobHMC6343.init()) {
      TCterminal.println("HMC6343 Magnetic Compass detected.");
      Serial2.println("HMC6343 Magnetic Compass detected.");
    } else {
      TCterminal.println("HMC6343 Magnetic Compass detection failed.");
      Serial2.println("HMC6343 Magnetic Compass detection failed.");
	}
#endif
    TCterminal.print("MMC5983MA Magnetic Compass ");
    Serial2.print("MMC5983MA Magnetic Compass ");
    if (MMC5983MAmag.begin()) {
      TCterminal.println("detected.");
      Serial2.println("detected.");
      MMC5983MAmag.softReset();
    } else {
      TCterminal.println("not detected.");
      Serial2.println("not detected.");
	}
  }
#ifdef __HMC6352__
  else { // Old Magnetic Compass online
    TCterminal.println("HMC6352 Magnetic Compass detected.");
    Serial2.println("HMC6352 Magnetic Compass detected.");
  }
#endif
  TCterminal.println("");
  Serial2.println("");
  TCterminal.println(hitkey);
  Serial2.println(hitkey);
  KEY();
  TCterminal.println("");
  Serial2.println("");


  // Test 9 - BME280 Temperature, Pressure,Humidity Sensor detection
  byte bme280_id = bme280.begin(); //Returns ID of 0x60 if successful
  TCterminal.print("\nBME280 Humidity, Barometric Pressure and Temperature sensor ");
  Serial2.print("\nBME280 Humidity, Barometric Pressure and Temperature sensor ");
  if (bme280_id != 0x60) { // Problem with BME280
    TCterminal.print("not ");
    Serial2.print("not ");
  }
  TCterminal.println("detected.");
  Serial2.println("detected.");
  TCterminal.println(hitkey);
  Serial2.println(hitkey);
  KEY();
  TCterminal.println("");
  Serial2.println("");


  // Test 10 - Azimuth Reference Sensor Detection
  TCterminal.println("\nAzimuth Reference Sensor check");
  Serial2.println("\nAzimuth Reference Sensor check");
  TCterminal.println(hitkey);
  Serial2.println(hitkey);
  while (!(TCterminal.available() || Serial2.available())) {
    TCterminal.print("Azimuth Reference Sensor is ");
    Serial2.print("Azimuth Reference Sensor is ");
    if (digitalRead(AZREFsensor) == LOW) {
      TCterminal.println("LOW ");
      Serial2.println("LOW ");
    } else {
      TCterminal.println("HIGH");
      Serial2.println("HIGH");
    }
    newdelay(500);
    ansi.cursorUp(1);
    ansi2.cursorUp(1);
  }
  KEY();
  TCterminal.println("");
  Serial2.println("");


  // Test 11 - Lock/Reinitialize Switch Detection
  TCterminal.println("\nLock/Reinitialize Switch check");
  Serial2.println("\nLock/Reinitialize Switch check");
  TCterminal.println(hitkey);
  Serial2.println(hitkey);
  while (!(TCterminal.available() || Serial2.available())) {
    TCterminal.print("Lock/Reinitialize Switch is ");
    Serial2.print("Lock/Reinitialize Switch is ");
    if (digitalRead(LOCKBTN) == LOW) {
      TCterminal.println("LOW ");
      Serial2.println("LOW ");
    } else {
      TCterminal.println("HIGH");
      Serial2.println("HIGH");
    }
    newdelay(500);
    ansi.cursorUp(1);
    ansi2.cursorUp(1);
  }
  KEY();
  TCterminal.println("");
  Serial2.println("");


  // Test 12 - Motor Driver Board detection and Motor test
  boolean motorDetected = false;
  i2cMotorDriver.settings.commInterface = I2C_MODE;
  i2cMotorDriver.settings.I2CAddress = MotorDriver_ADR;
  TCterminal.print("\nI2C Serial Controlled Motor Driver board ");
  Serial2.print("\nI2C Serial Controlled Motor Driver board ");
  if ( i2cMotorDriver.begin() != 0xA9 ) //See if a valid ID word is returned
  {
    TCterminal.print("not ");
    Serial2.print("not ");
  } else {
    motorDetected = true;
  }
  TCterminal.println("detected.");
  Serial2.println("detected.");
  if (motorDetected) {
    TCterminal.println("Waiting to enable outputs...");
    Serial2.println("Waiting to enable outputs...");
    while ( i2cMotorDriver.ready() == false );
    // Check for Azimuth motor inversion
#ifdef REVERSE_AZIMUTH_MOTOR_DIRECTION
    while( i2cMotorDriver.busy() ); //Waits until the SCMD is available.
    i2cMotorDriver.inversionMode(0, 1); //invert Azimuth motor
#endif
    // Check for Altitude motor inversion
#ifdef REVERSE_ALTITUDE_MOTOR_DIRECTION
    while ( i2cMotorDriver.busy() ); //Waits until the SCMD is available.
    i2cMotorDriver.inversionMode(1, 1); //invert Altitude motor
#endif
    while ( i2cMotorDriver.busy() );
    i2cMotorDriver.enable(); //Enables the output driver hardware
	
    TCterminal.println("\nHit Key to drive Azimuth motor CW for 10 seconds.");
    Serial2.println("\nHit Key to drive Azimuth motor CW for 10 seconds.");
    KEY();
    i2cMotorDriver.setDrive( AZIMUTH_MOTOR, CW_DIRECTION, FAST_SPEED );
    newdelay(10000);
    i2cMotorDriver.setDrive( AZIMUTH_MOTOR, 0, 0 );
    TCterminal.println("If motor moved CCW, uncomment line #define REVERSE_AZIMUTH_MOTOR_DIRECTION");
    Serial2.println("If motor moved CCW, uncomment line #define REVERSE_AZIMUTH_MOTOR_DIRECTION");

    TCterminal.println("\nHit Key to drive Altitude motor towards Zenith for 10 seconds.");
    Serial2.println("\nHit Key to drive Altitude motor towards Zenith for 10 seconds.");
    KEY();
    i2cMotorDriver.setDrive( ALTITUDE_MOTOR, CW_DIRECTION, FAST_SPEED );
    newdelay(10000);
    i2cMotorDriver.setDrive( ALTITUDE_MOTOR, 0, 0 );
    TCterminal.println("If motor moved towards Horizon, uncomment line #define REVERSE_ALTITUDE_MOTOR_DIRECTION");
    Serial2.println("If motor moved towards Horizon, uncomment line #define REVERSE_ALTITUDE_MOTOR_DIRECTION");
  }


  // Test 13 - IR Remote Receiver functionality check
  long xn;
  TCterminal.println("\nIR Remote Receiver functionality check");
  Serial2.println("\nIR Remote Receiver functionality check");
  TCterminal.println(hitkey);
  Serial2.println(hitkey);

  do {
    if (irrecv.getResults()) {
      irdecoder.decode();  //Decode it
      xn = irdecoder.value;
      if (xn != 0xffffffffL) {
        TCterminal.println(xn, HEX);
        Serial2.println(xn, HEX);
      }
      irrecv.enableIRIn(); // Receive the next value
    }
  } while (!(TCterminal.available() || Serial2.available()));
  KEY();

  TCterminal.println( "\n\nTests Completed\n" );
  Serial2.println( "\n\nTests Completed\n" );
}

void loop() {
  // to run repeatedly:
  while (1) ;
}

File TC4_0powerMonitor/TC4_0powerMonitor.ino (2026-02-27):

/* Arduino SAMD-based Telescope Controller 4.00.00 Optional Power Monitor - February 2026
// See MIT LICENSE.md file and ReadMe.md file for essential information
// Uses Sparkfun Micro OLED breakout, and Adafruit INA219 breakout
// to monitor Power Use when a 12 volt battery is used to provide system power.
*/
// I2C OLED display (IIC address 0x3c)
// I2C Voltage/Current sensor (IIC address 0x40)

// Account for Weirdness with SerialUSB
#if defined(ARDUINO_SAMD_ZERO) && defined(SERIAL_PORT_USBVIRTUAL)
#define Serial SERIAL_PORT_USBVIRTUAL
#endif

#include <Arduino.h>
#include "pins_arduino.h"
#include <Wire.h>
#include <stdint.h>
#include <string.h>
#include <math.h>
#include <SFE_MicroOLED.h>  // https://github.com/sparkfun/SparkFun_Micro_OLED_Arduino_Library
#include <Adafruit_INA219.h> // https://github.com/adafruit/Adafruit_INA219

//The OLED library assumes a reset pin is necessary.
//The Qwiic OLED has RST hard-wired, so pick an IO pin that is not being used */
const int PIN_RESET = 40; //This is for the Neo-Pixel LED, which isn't used
/* This OLED definition needed - The DC_JUMPER is the I2C Address Select jumper.
// Set to 1 if the jumper is open (Default), or set to 0 if it's closed. */
#define DC_JUMPER 1
MicroOLED oled(PIN_RESET, DC_JUMPER);    // I2C declaration
Adafruit_INA219 ina219; // Bus voltage monitor
// Keep track of total time and milliamp measurements for milliamp-hour computation.
uint32_t total_sec = 0;
float total_mA = 0.0;
float maxVoltage = 12.6; // Fully charged voltage
float minVoltage = 10.2; // Completely discharged voltage

void newdelay( long interval ) {
  // delay without blocking
  // See https://www.arduino.cc/en/tutorial/BlinkWithoutDelay
  // Generally, you should use "unsigned long" for variables that hold time
  // The value will quickly become too large for an int to store
  unsigned long previousMillis = millis();
  unsigned long currentMillis = millis();

  while (currentMillis - previousMillis < interval) {
    currentMillis = millis();
  }
}

uint8_t counter = 0;
void powerupdate() {
  if (counter == 0) {
    update_power_display();
  } else {
    counter = (counter+1) % 10 ;
  }
}

void setup() {
  // Try to initialize the INA219
  if (! ina219.begin()) {
    Serial.println("Failed to find INA219 chip");
    while (1) { delay(10); }
  }
  // By default the INA219 will be calibrated with a range of 32V, 2A.
  // However uncomment one of the below to change the range.  A smaller
  // range can't measure as large of values but will measure with slightly
  // better precision.
  ina219.setCalibration_16V_400mA();
  //ina219.setCalibration_32V_1A();

  newdelay(500);
	oled.begin();
  oled.clear(ALL);
  oled.display();
	newdelay(500);
  oled.clear(PAGE);
	oled.setFontType(0);
  oled.setCursor(0, 0);
  oled.print("  OLED    ");
	oled.print(" Battery  ");
  oled.print("  Power   ");
  oled.print(" Monitor  ");
	oled.print("TC 4.00.00");
	oled.display();
  newdelay(5000);
}

void loop() {
  // put your main code here, to run repeatedly:
  powerupdate();
  newdelay(5000);
}

void update_power_display() {
  // Read voltage and current from INA219.
  float shuntvoltage = ina219.getShuntVoltage_mV();
  float busvoltage = ina219.getBusVoltage_V();
  float current_mA = ina219.getCurrent_mA();

  // Compute load voltage, power, and milliamp-hours.
  float loadvoltage = busvoltage + (shuntvoltage / 1000);
  float power_mW = loadvoltage * current_mA;
  (void)power_mW;

  total_mA += current_mA;
  total_sec += 1;
  float total_mAH = total_mA / 3600.0;
  (void)total_mAH;
  
  // Calculate percentage (clamped between 0-100)
  float batteryPercentage = (loadvoltage - minVoltage) / (maxVoltage - minVoltage) * 100;
  if (batteryPercentage > 100) batteryPercentage = 100;
  else if (batteryPercentage < 0) batteryPercentage = 0;

  // Update display.
  oled.clear(PAGE);
  oled.setCursor(0,0);

  // Mode 0, display volts and amps.
  printSIValue(loadvoltage, "V:", 2, 10);
  oled.setCursor(0, 9);
  printSIValue(current_mA/1000.0, "A:", 5, 10);
  oled.setCursor(0, 18);
  printSIValue(total_mAH/1000.0, "AH:", 5, 10);
  oled.setCursor(0, 27);
  printSIValue(power_mW/1000.0, "W:", 5, 10);
  oled.setCursor(0, 36);
  printSIValue(batteryPercentage, "%:", 2, 10);
  oled.display();
}

void printSIValue(float value, const char* units, int precision, int maxWidth) {
  // Print a value in SI units with the units left justified and value right justified.
  // Will switch to milli prefix if value is below 1.

  // Add milli prefix if low value.
  if (fabs(value) < 1.0) {
    oled.print('m');
    maxWidth -= 1;
    value *= 1000.0;
    precision = max(0, precision-3);
  }

  // Print units.
  oled.print(units);
  maxWidth -= strlen(units);

  // Leave room for negative sign if value is negative.
  if (value < 0.0) {
    maxWidth -= 1;
  }

  // Find how many digits are in value.
  int digits = ceil(log10(fabs(value)));
  if (fabs(value) < 1.0) {
    digits = 1; // Leave room for 0 when value is below 0.
  }

  // Handle if not enough width to display value, just print dashes.
  if (digits > maxWidth) {
    // Fill width with dashes (and add extra dash for negative values);
    for (int i=0; i < maxWidth; ++i) {
      oled.print('-');
    }
    if (value < 0.0) {
      oled.print('-');
    }
    return;
  }

  // Compute actual precision for printed value based on space left after
  // printing digits and decimal point.  Clamp within 0 to desired precision.
  int actualPrecision = constrain(maxWidth-digits-1, 0, precision);

  // Compute how much padding to add to right justify.
  int padding = maxWidth-digits-1-actualPrecision;
  for (int i=0; i < padding; ++i) {
    oled.print(' ');
  }

  // Finally, print the value
  oled.print(value, actualPrecision);
}

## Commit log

2021-09-07 Update to 5 Sep 2021
    Has only Terminal code in place, and minus any motor/mount setup.
2022-06-20 Updated schematic and start motor implementation
    Updated schematic for Metro M4 use and start motor implementation
2022-07-03 Motor driver calls added
    Motor driver calls added and Diagnostics sketch expanded for motor and OLED testing
    [Telescope_Interface_shield.brd, Telescope_Interface_shield.sch]
2022-07-04 Remove old schematic PDF
    Remove old schematic PDF
2022-07-08 Add Magnetic North detection
    Added code to determine magnetic North, which is required for accurate Azimuth positioning when aiming at a celestial target position.
2022-07-12 Motor Update 1
    General update with some motor implementation, docs updated, etc.
2022-08-06 Speed Update for Terminal display
    Only check for GPS update once per minute, to prevent loading I2C too much. Diagram updated with more complete and consistent info. Some more motor support added.
    [TC4_0.ino, TC4_0diagnostics.ino, tcdervio.ino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]
2022-10-15 Correction to interface shield
    Correction to interface shield for Adafruit M4 Metro SAMD51 board that has 5V pin on ICSP connector
    [Telescope_Interface_shield.brd, Telescope_Interface_shield.sch]
2023-07-15 First batch of fixes
    Refactor documentation
    [TC4_0.ino, TC4_0diagnostics.ino, tcheader.h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]
2023-07-15 Update diagram power cord label
2023-07-15 Update Eagle schematic files
    [Telescope_Interface_shield.brd, Telescope_Interface_shield.sch]
2023-07-15 Rename Eagle directory to Arduino_Telescope_Interface
    [Telescope_Interface_shield.brd, Telescope_Interface_shield.sch]
2023-08-19 LCDdimmer and brighter syntax fixes
    [tcheader.h, tcvciofp.ino]
2023-08-29 More documentation changes, and LCD fixes
    [tcdervio.ino, tcheader.h, tcinit.ino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]
2026-02-27 latest changes in design, etc
    Update design to separate out power monitoring. Lots of other stuff too.
    [Telescope_Interface_shield.brd, Telescope_Interface_shield.sch]

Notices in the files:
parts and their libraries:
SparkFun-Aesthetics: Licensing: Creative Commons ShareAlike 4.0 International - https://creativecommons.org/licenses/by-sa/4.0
